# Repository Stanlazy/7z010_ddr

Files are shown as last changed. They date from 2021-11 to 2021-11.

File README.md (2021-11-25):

# 4-Layer XC7Z010 DDR3 Layout

A compact layout of XC7Z010 with DDR3.

Tested with DDR3L-1066 on PCB manufactured by JLC.

Traces are length matched to ±0.5mm with board thickness of 1.2mm

Package delay's equivalent length are calculated with dielectric constant of 4.05.

Traces are cutting reference plane? It works.™

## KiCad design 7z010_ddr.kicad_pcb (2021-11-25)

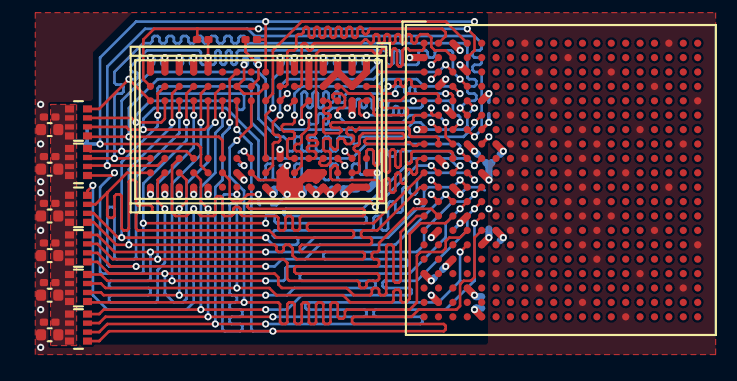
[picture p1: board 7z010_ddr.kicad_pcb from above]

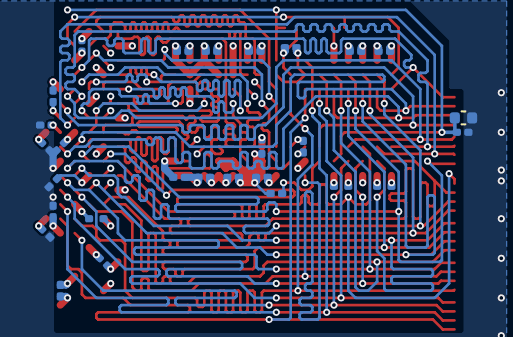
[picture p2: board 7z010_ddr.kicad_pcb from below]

Board: 4 copper layers, 50 parts (28 on the bottom side), 61 nets.

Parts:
C1, C2, C3, C4, C5, C7, C8, C9, C10, C11, C13, C14, C15, C16, C17, C18, C21, C23, C24, C25, C26, C28, C30, C33, C34, C35: C; C_0201_0603Metric
C6, C12, C20, C27, C32, C36, C37: C; C_0402_1005Metric
C19, C22, C29, C31: C; C_0201_0603Metric_WideGap
R1, R4, R5: 80Ω; R_0201_0603Metric
R2: 4K7Ω; R_0201_0603Metric
R3: 240Ω; R_0201_0603Metric
RN1, RN2, RN3, RN4, RN5, RN6: 40Ω; R_Array_Convex_4x0402
U1: DDR3; BGA-96_9.0x13.0mm_Layout2x3x16_P0.8mm_NoPaste
U2: xc7z010clg400; Xilinx_CLG400_NoPaste_JLC_Package_Delay

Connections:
/DDR_VRN: R4.1, U2.G5
/DDR_VRP: R5.1, U2.H5
/DDR_ZQ0: R3.2, U1.L8
DDR_A0: RN4.7, U1.N3, U2.N2
DDR_A1: RN3.8, U1.P7, U2.K2
DDR_A2: RN4.6, U1.P3, U2.M3
DDR_A3: RN2.5, U1.N2, U2.K3
DDR_A4: RN5.6, U1.P8, U2.M4
DDR_A5: RN3.5, U1.P2, U2.L1
DDR_A6: RN4.8, U1.R8, U2.L4
DDR_A7: RN3.6, U1.R2, U2.K4
DDR_A8: RN3.7, U1.T8, U2.K1
DDR_A9: RN1.7, U1.R3, U2.J4
DDR_A10: RN1.5, U1.L7, U2.F5
DDR_A11: RN2.6, U1.R7, U2.G4
DDR_A12: RN2.8, U1.N7, U2.E4
DDR_A13: RN1.8, U1.T3, U2.D4
DDR_A14: RN2.7, U1.T7, U2.F4
DDR_BA0: RN5.8, U1.M2, U2.L5
DDR_BA1: RN6.7, U1.N8, U2.R4
DDR_BA2: RN1.6, U1.M3, U2.J5
DDR_CK+: R1.1, U1.J7, U2.L2
DDR_CK-: R1.2, U1.K7, U2.M2
DDR_CKE: RN5.7, U1.K9, U2.N3
DDR_DQ0: U1.H8, U2.C3
DDR_DQ1: U1.F2, U2.B3
DDR_DQ2: U1.G2, U2.A2
DDR_DQ3: U1.H3, U2.A4
DDR_DQ4: U1.F7, U2.D3
DDR_DQ5: U1.E3, U2.D1
DDR_DQ6: U1.H7, U2.C1
DDR_DQ7: U1.F8, U2.E1
DDR_DQ8: U1.C2, U2.E2
DDR_DQ9: U1.A2, U2.E3
DDR_DQ10: U1.A3, U2.G3
DDR_DQ11: U1.C3, U2.H3
DDR_DQ12: U1.A7, U2.J3
DDR_DQ13: U1.D7, U2.H2
DDR_DQ14: U1.B8, U2.H1
DDR_DQ15: U1.C8, U2.J1
DDR_DQM0: U1.E7, U2.A1
DDR_DQM1: U1.D3, U2.F1
DDR_DQS0+: U1.F3, U2.C2
DDR_DQS0-: U1.G3, U2.B2
DDR_DQS1+: U1.C7, U2.G2
DDR_DQS1-: U1.B7, U2.F2
DDR_ODT: RN6.6, U1.K1, U2.N5
DDR_nCAS: RN6.5, U1.K3, U2.P5
DDR_nCS: RN4.5, U1.L2, U2.N1
DDR_nRAS: RN5.5, U1.J3, U2.P4
DDR_nRST: R2.1, U1.T2, U2.B4
DDR_nWE: RN6.8, U1.L3, U2.M5
GND: C1.2, C2.2, C3.2, C4.2, C5.2, C6.2, C7.2, C8.2, C9.2, C10.2, C11.2, C12.2, C13.2, C14.2, C15.2, C16.2, C17.2, C18.2, C19.2, C20.2, C21.2, C22.2, C23.2, C24.2, C25.2, C26.2, C27.2, C28.2, C29.2, C30.2, C31.2, C32.2, C33.2, C34.2, C35.2, C36.2, C37.2, R2.2, R3.1, R5.2, U1.A9, U1.B1, U1.B3, U1.B9, U1.D1, U1.D8, U1.E1, U1.E2, U1.E8, U1.F9, U1.G1, U1.G8, U1.G9, U1.J2, U1.J8, U1.M1, U1.M9, U1.P1, U1.P9, U1.T1, U1.T9, U2.A8, U2.A18, U2.B1, U2.B11, U2.C4, U2.C9, U2.C14, U2.D17, U2.E10, U2.E20, U2.F3, U2.F7, U2.G10, U2.G12, U2.G16, U2.H7, U2.H9, U2.H11, U2.H13, U2.H19, U2.J2, U2.J8, U2.J12, U2.K5, U2.K7, U2.K11, U2.K13, U2.K15, U2.L8, U2.L12, U2.L18, U2.M1, U2.M7, U2.M11, U2.M13, U2.N4, U2.N8, U2.N10, U2.N12, U2.N14, U2.P7, U2.P9, U2.P11, U2.P13, U2.P17, U2.R8, U2.R12, U2.R20, U2.T3, U2.T7, U2.T13, U2.U6, U2.U16, U2.V9, U2.V19, U2.W2, U2.W12, U2.Y5, U2.Y15
unnamed: U2.F8, U2.G9, U2.H8, U2.K8, U2.M8
unnamed: U2.G7, U2.J7, U2.L7, U2.N7, U2.P8, U2.R7
unnamed: U2.G11, U2.H10
unnamed: U2.G13, U2.H12, U2.J13, U2.K12, U2.L13, U2.M12, U2.N13, U2.P12, U2.R13
unnamed: U2.J11, U2.L11, U2.N9, U2.N11, U2.P10, U2.R9
VCC_DDR: C2.1, C3.1, C4.1, C5.1, C7.1, C8.1, C10.1, C11.1, C13.1, C14.1, C15.1, C16.1, C18.1, C19.1, C21.1, C22.1, C24.1, C26.1, C29.1, C31.1, R4.2, U1.A1, U1.A8, U1.B2, U1.C1, U1.C9, U1.D2, U1.D9, U1.E9, U1.F1, U1.G7, U1.H2, U1.H9, U1.K2, U1.K8, U1.N1, U1.N9, U1.R1, U1.R9, U2.A3, U2.D2, U2.E5, U2.G1, U2.H4, U2.L3, U2.P2, U2.R5, U2.U1, U2.V4
VREF_DDR: C25.1, C28.1, C33.1, C34.1, C36.1, U1.H1, U1.M8, U2.H6, U2.P6
VTT_DDR: C1.1, C6.1, C9.1, C12.1, C17.1, C20.1, C23.1, C27.1, C30.1, C32.1, C35.1, C37.1, RN1.1, RN1.2, RN1.3, RN1.4, RN2.1, RN2.2, RN2.3, RN2.4, RN3.1, RN3.2, RN3.3, RN3.4, RN4.1, RN4.2, RN4.3, RN4.4, RN5.1, RN5.2, RN5.3, RN5.4, RN6.1, RN6.2, RN6.3, RN6.4

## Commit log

2021-11-24 initial upload
    [7z010_ddr.kicad_pcb, 7z010_ddr.sch]
2021-11-24 update termination resistor value
    [7z010_ddr.sch]
2021-11-25 added GND back to sch
    [7z010_ddr.kicad_pcb, 7z010_ddr.sch]
2021-11-25 move symbols to project library
    [7z010_ddr.sch]
2021-11-25 fix power rail junction
    [7z010_ddr.sch]

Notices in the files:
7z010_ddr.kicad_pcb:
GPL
